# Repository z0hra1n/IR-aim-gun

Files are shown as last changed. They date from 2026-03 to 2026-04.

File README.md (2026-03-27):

This is a gun peripheral for fps games with a recoil mechanism and tactile reload and a joystick for movement inspired by the wii remote.

I made this project because it has been going in my head for a while i just wondered why has no one made it yet.I did want to make it before but i didnt have the funding now with stasis, im making it real.The recoil mechanism was inspired by my little brother's toy gun.







311 02 00_product_image_left

## Bill of Materials

| Purpose | Component / Item | Qty | Total Cost (USD) | Distributor | Link |
|---|---|-----|---|---|---|
| Solenoid driver control | PCB (JLCPCB) | 1 | 2.10 | JLCPCB | https://cart.jlcpcb.com/quote?rand=0.9395806180197926 |
| Solenoid driver board | Driver Module | 1 | 0.39 | Robu.in | https://robu.in/product/1-month-warranty-1004/ |
| Solenoid driver board | 10kΩ SMD Resistors (0805, pack) | 10  | 0.02 | Robu.in | https://robu.in/product/10k-ohm-1-4w-0805-surface-mount-chip-resistor-pack-of-10/ |
| Solenoid driver board | 220Ω SMD Resistors (0805, pack) | 10  | 0.04 | Robu.in | https://robu.in/product/rc0805fr-07220rlyageores-smd-220-ohm-5-1-2w-0805/ |
| Main casing | 3D Printing Service | 1 | 6.63 | Robu.in | https://robu.in/product/3d-printing-service/ |
| Solenoid driving | IRLZ44N MOSFET | 1 | 0.42 | Robu.in | https://robu.in/product/irlz44n/ |
| Recoil mechanism | Push-Pull Solenoid | 1 | 5.90 | Amazon | https://www.amazon.in/xcluma-JF-0826B-Push-Pull-Solenoid-Electromagnet/dp/B09XK2MBQP/ |
| Power supply | 1500mAh Li-Po Battery | 1 | 3.00 | Robu.in | https://robu.in/product/1500mah-pcm-protected-micro-li-po-battery/ |
| Voltage stabilization | 1000µF Capacitor | 1 | 0.12 | Robu.in | https://robu.in/product/1000uf-25v-electrolytic-capacitor-dip-pack-of-5/ |
| Voltage conversion | 3.7V to 5V Boost Converter | 1 | 0.85 | Robu.in | https://robu.in/product/3-7v-to-9v-5v-2a-multimeter-modified-charger-boost/ |
| User input (trigger & reload) | Push Button Switches | 5 | 1.05 | Robu.in | https://robu.in/product/red-r13-507-16mm-no-lock-push-button-momentary-switch-3a-250v/ |
| IR emission | IR LED Emitter Module | 1 | 3.43 | Amazon | https://www.amazon.in/Invento-Emitter-Transmitter-Infrared-Projects/dp/B07GD1JDR6/ |
| Cursor positioning | IR Positioning Camera (DFRobot) | 1 | 23.90 | Robu.in | https://robu.in/product/dfrobot-gravity-ir-positioning-camera-for-arduino/ |
| For movement in games. | Joystick module | 1 | 0.39 | Robu.in |https://robu.in/product/joystick-module-ps2-breakout-sensor/ |

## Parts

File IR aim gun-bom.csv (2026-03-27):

Name | Purpose | Quantity | Total Cost (USD) | Link | Distributor
Joystick module | For movement in games. | 1 | 0.39 | https://robu.in/product/joystick-module-ps2-breakout-sensor/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 | Robu.in
Solenoid driver board | For driving the solenoid | 1 | 2.10 | https://cart.jlcpcb.com/quote?rand=0.9395806180197926 | jlcpcb
Header male pins | For the driver solenoid board | 1 | 0.39 | https://robu.in/product/1-month-warranty-1004/ | Robu.in
10k resistor | for the solenoid driver board | 10 | 0.02 | https://robu.in/product/10k-ohm-1-4w-0805-surface-mount-chip-resistor-pack-of-10/ | Robu.in
220 ohms resistor | for the solenoid driver board | 10 | 0.04 | https://robu.in/product/rc0805fr-07220rlyageores-smd-220-ohm-5-1-2w-0805/ | Robu.in
3d print | the casing of the whole project. | 1 | 6.63 | https://robu.in/product/3d-printing-service/ | Robu.in
Mosfet | for driving the solenoid | 1 | 0.42 | https://robu.in/product/irlz44n/ | Robu.in
Solenoid | For recoil | 1 | 5.90 | https://www.amazon.in/xcluma-JF-0826B-Push-Pull-Solenoid-Electromagnet/dp/B09XK2MBQP?s=industrial | Amazon
Battery | for power | 1 | 3.00 | https://robu.in/product/1500mah-pcm-protected-micro-li-po-battery/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 | Robu.in
Capacitor | for smoothening out solenoid spikes | 1 | 0.12 | https://robu.in/product/1000uf-25v-electrolytic-capacitor-dip-pack-of-5/ | Robu.in
boost converter | For converting 3.7v to 5v | 1 | 0.85 | https://robu.in/product/3-7v-to-9v-5v-2a-multimeter-modified-charger-boost/ | Robu.in
momentary push button | For the reload, trigger. | 5 | 1.05 | https://robu.in/product/red-r13-507-16mm-no-lock-push-button-momentary-switch-3a-250v/ | Robu.in
IR emitter leds | for emitting ir light so that the camera receives it. | 1 | 3.43 | https://www.amazon.in/Invento-Emitter-Transmitter-Infrared-Projects/dp/B07GD1JDR6 | Amazon
IR camera | For positioning of the cursor. | 1 | 23.90 | https://robu.in/product/dfrobot-gravity-ir-positioning-camera-for-arduino/ | Robu.in

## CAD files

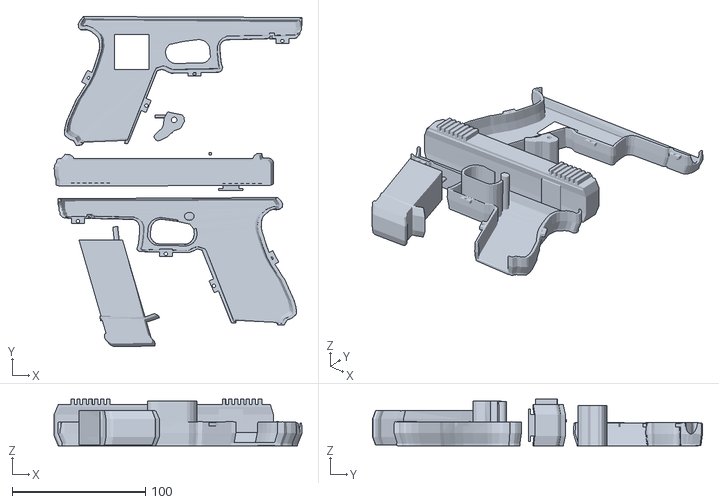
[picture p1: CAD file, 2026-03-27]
3D MODELS/FINALGUNPRINT.stl
185.6 x 247.2 x 35.1

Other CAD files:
3D MODELS/GUN.blend

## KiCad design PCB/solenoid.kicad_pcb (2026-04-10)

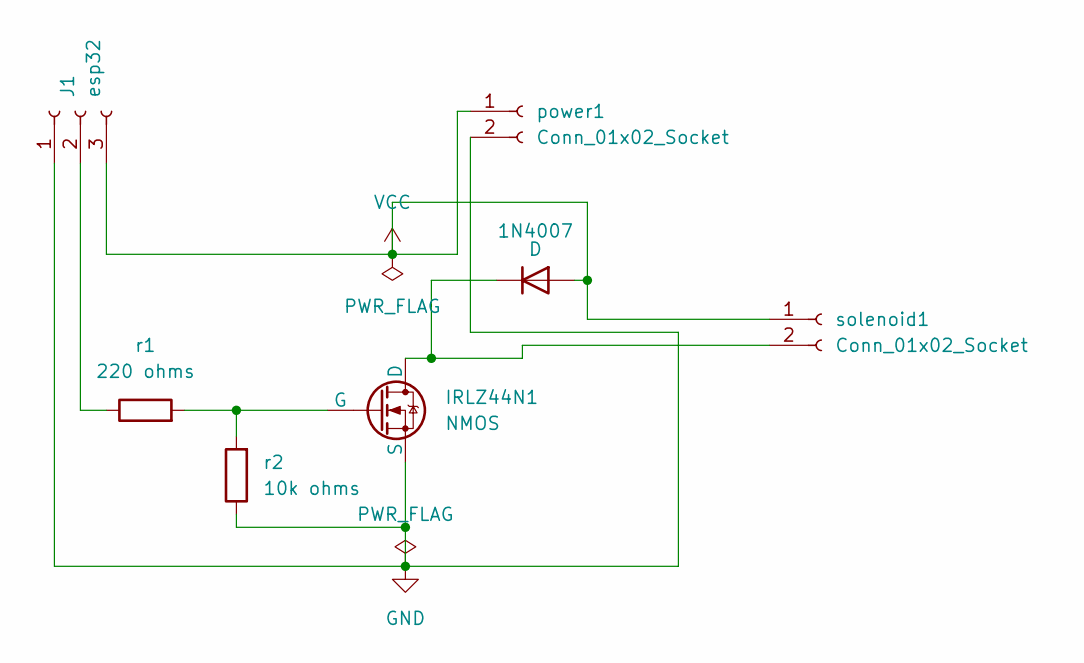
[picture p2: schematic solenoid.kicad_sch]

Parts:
1N4007: D; D_SMA; LCSC Part # C20754788
IRLZ44N1: NMOS; TO-220-3_Vertical
J1: esp32; PinHeader_1x03_P2.54mm_Vertical
power1: Conn_01x02_Socket; PinSocket_1x02_P2.54mm_Vertical
r1: 220 ohms; R_0805_2012Metric; LCSC Part # C17557
r2: 10k ohms; R_0805_2012Metric; LCSC Part # C84376
solenoid1: Conn_01x02_Socket; PinSocket_1x02_P2.54mm_Vertical

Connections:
GND: IRLZ44N1.3 (S), J1.1, power1.2, r2.1
unnamed: 1N4007.1 (K), IRLZ44N1.1 (D), solenoid1.2
unnamed: IRLZ44N1.2 (G), r1.2, r2.2
unnamed: J1.2, r1.1
VCC: 1N4007.2 (A), J1.3, power1.1, solenoid1.1

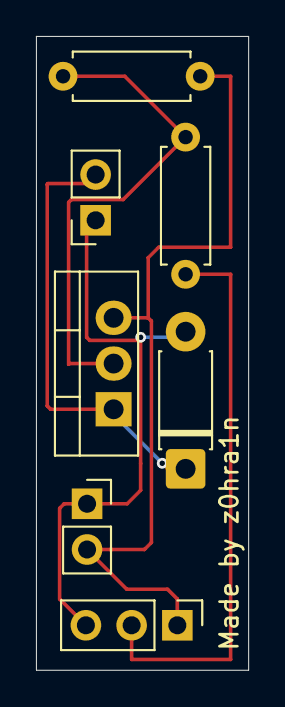
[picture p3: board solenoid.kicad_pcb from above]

Board: 2 copper layers, 11.8 x 35.2 mm, 7 parts (0 on the bottom side), 5 nets.

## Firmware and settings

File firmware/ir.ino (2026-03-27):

#include <Wire.h>
#include <BleCombo.h>

BleCombo bleCombo;

#define joyX 34
#define joyY 36

#define triggerPin 25
#define reloadPin 26
#define solenoidPin 27

int IRsensorAddress = 0xB0;
int slaveAddress = IRsensorAddress >> 1;

int threshold = 800;

byte data_buf[16];
int Ix[4];
int Iy[4];
int s;

bool solenoid = false;

void Write_2bytes(byte d1, byte d2){
Wire.beginTransmission(slaveAddress);
Wire.write(d1);
Wire.write(d2);
Wire.endTransmission();
}

void setup() {
Serial.begin(115200);
Wire.begin();

pinMode(triggerPin, INPUT_PULLUP);
pinMode(reloadPin, INPUT_PULLUP);
pinMode(solenoidPin, OUTPUT);

digitalWrite(solenoidPin, LOW);

bleCombo.begin();

Write_2bytes(0x30,0x01); delay(10);
Write_2bytes(0x30,0x08); delay(10);
Write_2bytes(0x06,0x90); delay(10);
Write_2bytes(0x08,0xC0); delay(10);
Write_2bytes(0x1A,0x40); delay(10);
Write_2bytes(0x33,0x33); delay(10);
delay(100);
}

void loop() {

solenoid = digitalRead(triggerPin) == HIGH;
digitalWrite(solenoidPin, solenoid ? HIGH : LOW);

if(bleCombo.isConnected()){
if(solenoid) bleCombo.press(MOUSE_LEFT);
else bleCombo.release(MOUSE_LEFT);
}

if(digitalRead(reloadPin) == HIGH && bleCombo.isConnected()){
bleCombo.press('r');
delay(100);
bleCombo.release('r');
}

int dx = analogRead(joyX);
int dy = analogRead(joyY);

int jx = dx - 2048;
int jy = dy - 2048;

if(abs(jx) < threshold) jx = 0;
if(abs(jy) < threshold) jy = 0;

if(bleCombo.isConnected()){

```
bleCombo.release('w');
bleCombo.release('a');
bleCombo.release('s');
bleCombo.release('d');

if(jy > threshold) bleCombo.press('w');
if(jy < -threshold) bleCombo.press('s');

if(jx > threshold) bleCombo.press('d');
if(jx < -threshold) bleCombo.press('a');
```

}

Wire.beginTransmission(slaveAddress);
Wire.write(0x36);
Wire.endTransmission();
Wire.requestFrom(slaveAddress, 16);

int i = 0;
while(Wire.available() && i < 16){
data_buf[i] = Wire.read();
i++;
}

Ix[0] = data_buf[1];
Iy[0] = data_buf[2];
s = data_buf[3];

Ix[0] += (s & 0x30) << 4;
Iy[0] += (s & 0xC0) << 2;

Serial.print("X=");
Serial.print(Ix[0]);
Serial.print(" Y=");
Serial.println(Iy[0]);

if(bleCombo.isConnected()){
int deltaX = map(Ix[0], 0, 1023, -5, 5);
int deltaY = map(Iy[0], 0, 767, -5, 5);
bleCombo.move(deltaX, deltaY);
}

delay(50);
}

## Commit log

2026-03-23 Add Bill of Materials to README
    Added a Bill of Materials section with components, quantities, costs, and links.
2026-03-27 Rename IR aim gun-bom (1).csv to IR aim gun-bom.csv
    [IR aim gun-bom.csv]
